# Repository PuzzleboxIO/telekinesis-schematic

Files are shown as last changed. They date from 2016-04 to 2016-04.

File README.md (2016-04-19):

EEG design based on the 8-bit OpenBCI with a TI ADS1299 and an Intel Curie Module

For more information please visit:

http://puzzlebox.io/telekinesis

Contributors:

Tomás Vega [https://github.com/tomasero]

Kelly Peng [https://github.com/GameCracker]

Design software format:

EAGLE PCB

Screenshots:





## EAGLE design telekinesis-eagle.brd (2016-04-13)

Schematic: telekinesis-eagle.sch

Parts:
BATT: JST_2PIN; JSTPH2
C1, C25, C31, C33, C40: 10 uF; C0805K
C2: 100 uF; C/6032-28R
C3, C9, C11, C28, C35: CKCL44X7R1H102M0B5AA; CKCL44
C5, C6, C7, C14, C17, C18, C19, C21, C22, C29: 1 uF; C0805K
C12, C13, C15, C24, C26, C27, C30, C46: 0.1 uF; C0805K
C16: 1 nF; C0805K
C20, C23: 9 pF; C0805K
C32: 0.01 uF; C0805K
C34, C36, C37, C39, C41, C43, C44, C45: 2.2 uF; C0805K
C38: 0.01uF; C0805K
C42: 100 uF; C0805K
D2, D3, D4, D5, D6, D7: QUAD_TVS
D8: BLUE; SML0603
D9: DIODESOD-123; SOD-123
IC1: MEGA8-AI; TQFP32-08
IC2: IC_BUFF_SN74LVC8T245; SOIC-24
PROGRAM: DPDT; AYZ0202
R1, R2, R3, R4, R6: 2.2k; CAY16
R5: 1M; R0805W
R8: 10K; R0805W
R9: 470K; R0805W
R12: 1K; R0805W
S1: SWITCH-MOMENTARY-2SMD-REDUNDANT; TACTILE-SWITCH-SMD
SV1: MA13-2W
SW1: SWITCH_SPST; SPST_SMT_19192
U3: LM2664; SOT-23-6
U4: TLV700XX; SC70-5
U5, U9: LP5907
U6: ADS_1299; TQFP64_ADS
U$5: ORB_0; ORB_52_22MM
UART: M03PTH; 1X03
UARTCONNECT: DPDT; AYZ0202
VR1: TPS72325; SM
X1: CSM-7X-DU

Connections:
1N: D3.4 (IO3), R1.1, SV1.21
1P: D2.1 (IO1), R1.2 (1), SV1.22
2N: D3.2 (IO2), R2.3 (1), SV1.19
2P: D3.5 (IO4), R2.4 (1), SV1.20
3N: D4.4 (IO3), R2.1, SV1.17
3P: D3.1 (IO1), R2.2 (1), SV1.18
4N: D4.2 (IO2), R3.3 (1), SV1.15
4P: D4.5 (IO4), R3.4 (1), SV1.16
5N: D5.4 (IO3), R3.1, SV1.13
5P: D4.1 (IO1), R3.2 (1), SV1.14
6N: D5.2 (IO2), R4.3 (1), SV1.11
6P: D5.5 (IO4), R4.4 (1), SV1.12
7N: D6.4 (IO3), R4.1, SV1.9
7P: D5.1 (IO1), R4.2 (1), SV1.10
8N: D6.2 (IO2), R6.3 (1), SV1.7
8P: D6.5 (IO4), R6.4 (1), SV1.8
+5V: C26.1, C39.2, C41.2, C42.2, C44.2, IC1.4 (VCC), IC1.6 (VCC), IC1.18 (AVCC), IC2.24 (VCCB1), R8.2, R9.2, U3.4 (SD), U3.5 (V+), U4.1 (IN), U4.3 (EN), U5.1 (VIN), U5.3 (EN), U9.5 (OUT), U$5.26 (36)
+UB: C13.1, C17.1, C22.1, C24.1, C29.1, C30.1, C36.2, C40.1, D7.2 (IO2), SV1.1, SV1.2, U4.5 (OUT), U6.19 (AVDD3), U6.21 (AVDD4), U6.22 (AVDD), U6.35 (/PWDN), U6.54 (AVDD_1), U6.56 (AVDD2), U6.59 (AVDD1)
-RAW: C33.1, C37.2, U3.2 (OUT), VR1.2 (IN), VR1.3 (EN)
-UB: C1.1, C2.-, C5.1, C6.2, C7.2, C13.2, C15.1, C17.2, C18.1, C19.1, C21.1, C31.1, C34.2, D2.4 (IO3), SV1.25, SV1.26, U6.20 (AVSS2), U6.23 (AVSS1), U6.25 (VREFN), U6.32 (AVSS), U6.53 (AVSS_1), U6.57 (AVSS3), U6.58 (AVSS4), VR1.5 (OUT)
A0: IC1.23 (PC0(ADC0))
A1: IC1.24 (PC1(ADC1))
A2: IC1.25 (PC2(ADC2))
A3: IC1.26 (PC3(ADC3))
A6: IC1.19 (ADC6)
A7: IC1.22 (ADC7)
ARDUINO_RESET: C46.2, IC1.29 (PC6(/RESET)), R8.1, S1.3 (2), S1.4 (2)
AREF: C27.1, IC1.20 (AREF)
BIAS: D7.4 (IO3), R6.1, SV1.5, SV1.6
BIAS_DRV: C16.2, C35.8, R5.2, R6.8 (2)
BIAS_INV: U6.61 (BIAS_INV)
BOOT_EN: C46.1
CLK: U6.37 (CLK)
CS1: IC2.8 (A6), U6.39 (/CS)
CS2: IC2.6 (A4)
CS3: IC2.5 (A3)
CS4: IC2.4 (A2)
DVDD: C12.1, C14.1, C43.2, IC2.1 (VCCA), U5.5 (OUT), U6.48 (DVDD2), U6.50 (DVDD1), U6.52 (CLKSEL)
GND: C3.1, C3.2, C3.3, C3.4, C9.1, C9.2, C9.3, C9.4, C11.1, C11.2, C11.3, C11.4, C12.2, C14.2, C18.2, C21.2, C22.2, C24.2, C28.1, C28.2, C28.3, C28.4, C29.2, C30.2, C31.2, C32.1, C33.2, C34.1, C35.1, C35.2, C35.3, C35.4, C36.1, C37.1, C38.1, C39.1, C40.2, C41.1, C42.1, C43.1, C44.1, C45.1, D2.3 (GND), D3.3 (GND), D4.3 (GND), D5.3 (GND), D6.3 (GND), D7.1 (IO1), D7.3 (GND), D9.A, IC2.2 (DIR), IC2.11 (GND1), IC2.12 (GND2), IC2.13 (GND3), IC2.22 (OE), R6.2 (1), R6.7 (2), R12.1, SV1.3, SV1.4, U3.1 (GND), U4.2 (GND), U5.2 (GND), U6.31 (RESV1), U6.33 (DGND), U6.41 (DAISY_IN), U6.49 (DGND1), U6.51 (DGND2), U6.60 (BIAS_REF), U6.64 (RESERVED), U9.2 (GND), U$5.1 (47), UART.3, VR1.1 (GND)
IN1N: C3.8, R1.8 (2), U6.15 (IN1N)
IN1P: C3.7, R1.7 (2), U6.16 (IN1P)
IN2N: C9.6, R2.6 (2), U6.13 (IN2N)
IN2P: C9.5, R2.5 (2), U6.14 (IN2P)
IN3N: C9.8, R2.8 (2), U6.11 (IN3N)
IN3P: C9.7, R2.7 (2), U6.12 (IN3P)
IN4N: C11.6, R3.6 (2), U6.9 (IN4N)
IN4P: C11.5, R3.5 (2), U6.10 (IN4P)
IN5N: C11.8, R3.8 (2), U6.7 (IN5N)
IN5P: C11.7, R3.7 (2), U6.8 (IN5P)
IN6N: C28.6, R4.6 (2), U6.5 (IN6N)
IN6P: C28.5, R4.5 (2), U6.6 (IN6P)
IN7N: C28.8, R4.8 (2), U6.3 (IN7N)
IN7P: C28.7, R4.7 (2), U6.4 (IN7P)
IN8N: C35.6, R6.6 (2), U6.1 (IN8N)
IN8P: C35.5, R6.5 (2), U6.2 (IN8P)
MOSI: IC2.9 (A7), U6.34 (D_IN)
unnamed: IC1.32 (PD2(INT0)), R9.1
unnamed: C20.2, IC1.7 (PB6(XTAL1/TOSC1)), X1.2
unnamed: C23.2, IC1.8 (PB7(XTAL2/TOSC2)), X1.1
unnamed: C16.1, R5.1, U6.62 (BIAS_IN), U6.63 (BIAS_OUT)
unnamed: C15.2, C19.2, U6.55 (VCAP3)
unnamed: C6.1, U6.26 (VCAP4)
unnamed: C1.2, C5.2, U6.24 (VREFP)
unnamed: C2.+, U6.28 (VCAP1)
unnamed: C25.1, U3.6 (CAP+)
unnamed: C7.1, U6.30 (VCAP2)
unnamed: C25.2, U3.3 (CAP-)
unnamed: C32.2, VR1.4 (NR)
unnamed: D8.C, R12.2
unnamed: C38.2, U9.4 (NC)
NC: IC2.23 (VCCB2), U6.27 (NC1), U6.29 (NC)
NULL: BATT.1, D9.C
PE: C20.1, C23.1, C26.2, C27.2, IC1.3 (GND), IC1.5 (GND), IC1.21 (GND), S1.1, S1.2 (1)
RAW: BATT.2, SW1.B
RAW_SWITCH: C45.2, SW1.C (S), U9.1 (VIN), U9.3 (EN)
RESET: IC2.7 (A5), U6.36 (/RESET)
RX: PROGRAM.2, UART.2
RX_ATM: IC1.30 (PD0(RXD)), PROGRAM.4, UARTCONNECT.5
RX_ORB: PROGRAM.6, U$5.33 (17), UARTCONNECT.1
SCL: IC1.28 (PC5(ADC5/SCL)), U$5.10 (9)
SCLK: D8.A, IC2.10 (A8), U6.40 (SCLK)
SDA: IC1.27 (PC4(ADC4/SDA)), U$5.9 (8)
SRB1: D2.5 (IO4), R1.4 (1), SV1.24
SRB2: D2.2 (IO2), R1.3 (1), SV1.23
TX: PROGRAM.5, UART.1
TXD: IC2.3 (A1)
TX_ATM: IC1.31 (PD1(TXD)), IC2.21 (B1), PROGRAM.1, UARTCONNECT.2
TX_ORB: PROGRAM.3, U$5.31 (19), UARTCONNECT.4
_CS1: IC1.14 (PB2(SS/OC1B)), IC2.16 (B6)
_CS2: IC1.11 (PD7(AIN1)), IC2.18 (B4)
_CS3: IC1.10 (PD6(AIN0)), IC2.19 (B3)
_CS4: IC1.9 (PD5(T1)), IC2.20 (B2)
_DRDY: IC1.12 (PB0(ICP)), U6.47 (/DRDY)
_INT1: IC1.1 (PD3(INT1))
_MISO: IC1.16 (PB4(MISO)), U6.43 (DOUT)
_MOSI: IC1.15 (PB3(MOSI/OC2)), IC2.15 (B7)
_RESET: IC1.13 (PB1(OC1A)), IC2.17 (B5)
_SCLK: IC1.17 (PB5(SCK)), IC2.14 (B8)
_SRB1: C3.5, R1.5 (2), U6.17 (SRB1)
_SRB2: C3.6, R1.6 (2), U6.18 (SRB2)

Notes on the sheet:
5V Regulator
2.5V Regulator
-2.5V Regulator
Input Connector
ADS1299
ATmega328
5V Inverter
ADS Decoupling
Blue Led
Filtro
3V Regulator
Intel Curie

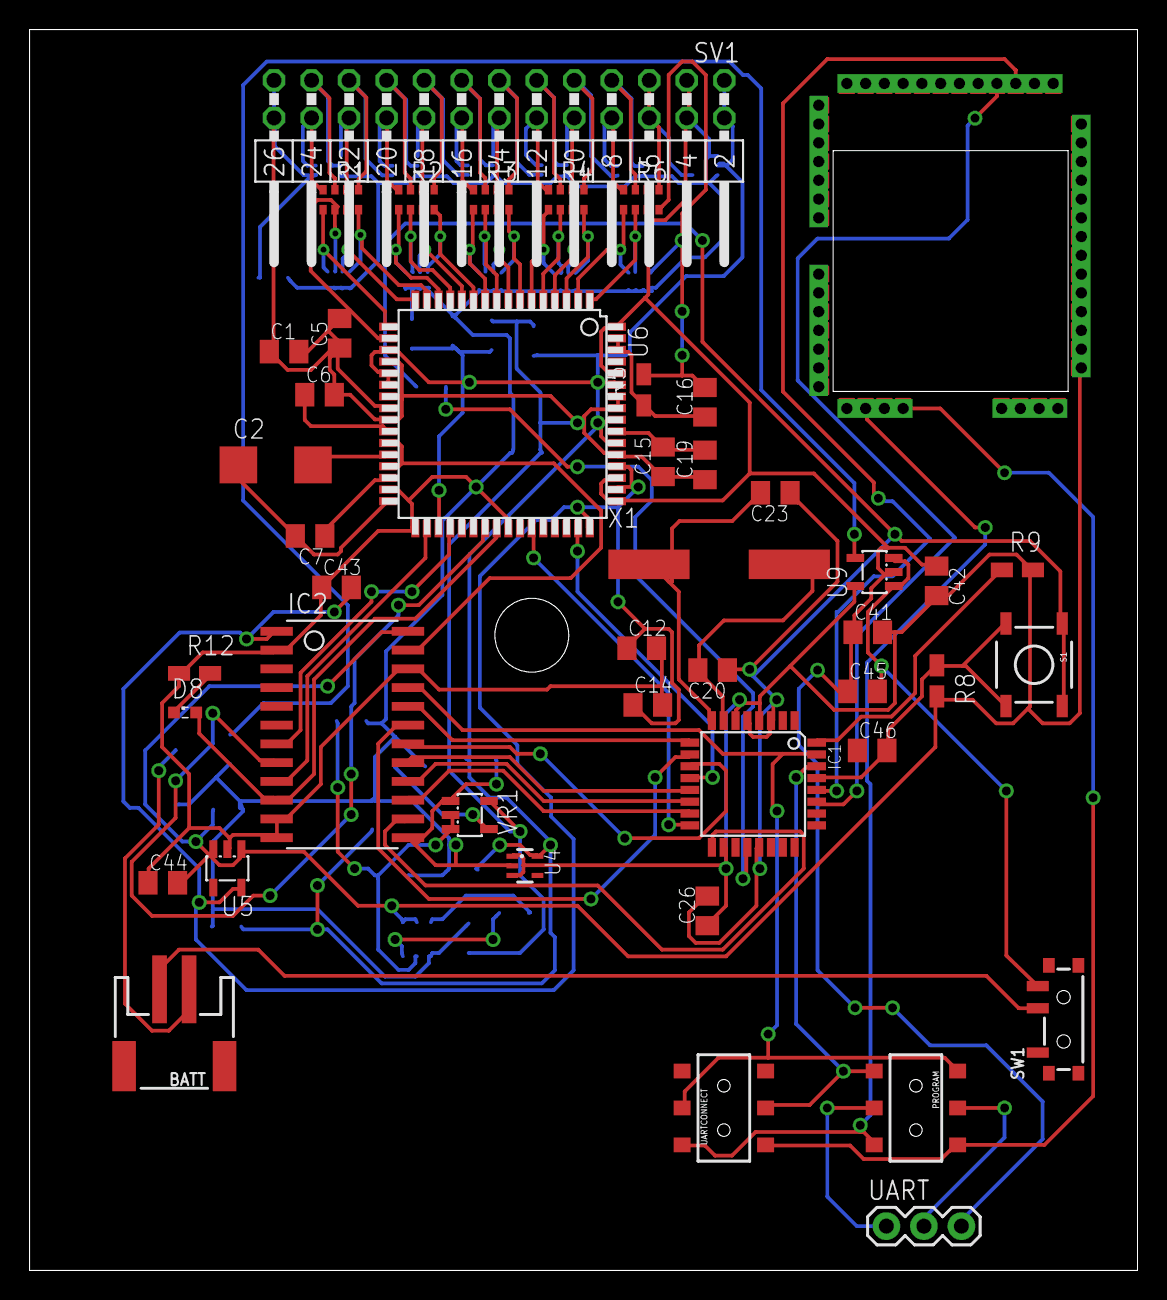
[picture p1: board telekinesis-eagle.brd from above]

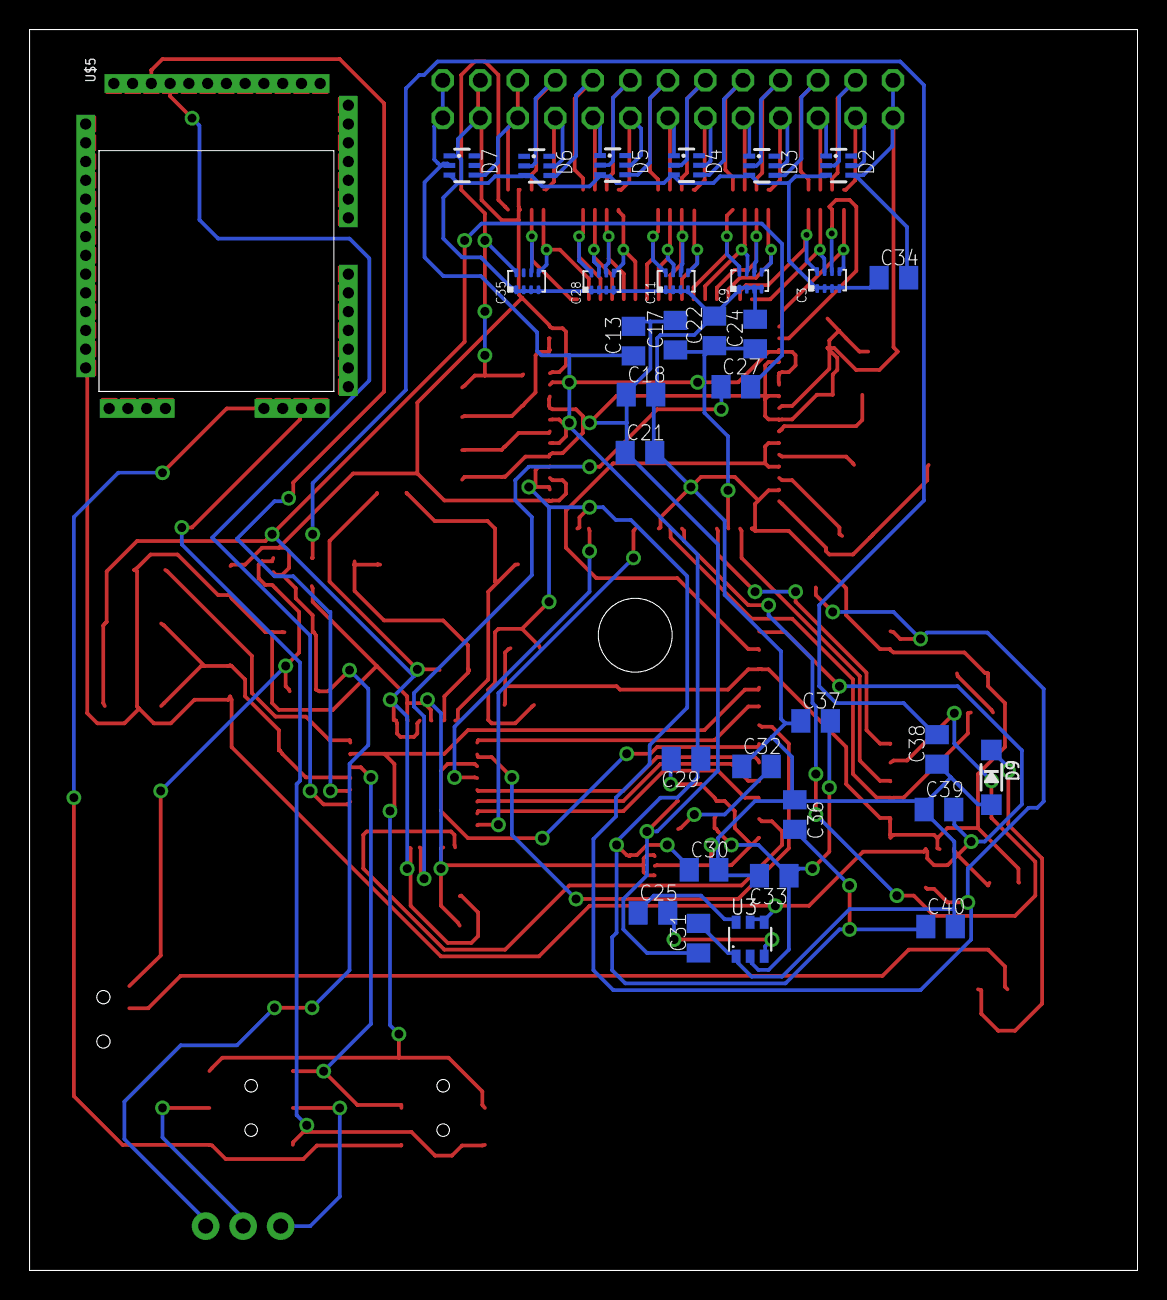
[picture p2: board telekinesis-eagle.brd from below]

Board: 2 copper layers, 75.0 x 84.0 mm, 77 parts (33 on the bottom side), 86 nets.

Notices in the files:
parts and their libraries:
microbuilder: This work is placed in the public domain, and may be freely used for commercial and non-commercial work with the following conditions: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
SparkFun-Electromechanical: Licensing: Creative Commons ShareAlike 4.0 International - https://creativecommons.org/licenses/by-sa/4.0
